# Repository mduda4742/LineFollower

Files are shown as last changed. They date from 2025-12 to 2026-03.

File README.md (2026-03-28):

# LineFollower

This project presents an autonomous Line Follower robot built around the STM32 NUCLEO-L476RG platform. The main objective is fast and accurate tracking of a black line on a white surface.

The work includes:
- 3D modeling of the robot and custom parts
- 3D printing and mechanical assembly
- PID controller implementation and tuning on NUCLEO-L476RG
- Electrical schematic design and integration of all electronic modules

## Project Overview

The robot uses a reflective sensor array to estimate the line position in real time. Based on sensor readings, a PID controller computes the correction signal and adjusts DC motor speeds independently. This approach improves cornering stability, reduces oscillations, and enables smoother trajectory tracking.

Power is provided by two Li-Ion cells, and firmware development is done in STM32CubeIDE.

## Mechanical Design (3D CAD + Printing)

The mechanical part of the project was designed as a custom 3D model and manufactured with 3D-printed components. The repository contains CAD files for the chassis and mounting elements in the `Mechanics/` directory.

## Control System (PID on STM32 NUCLEO-L476RG)

The control firmware is implemented in C for STM32L476RG. The key part is PID parameter tuning to balance:
- fast response
- stable line tracking
- minimal overshoot during turns

Firmware sources are located in `Firmware/Core/Src/` and headers in `Firmware/Core/Inc/`.

## Electrical Design

The project also includes electrical schematic development for power distribution, sensor connections, motor driving, and microcontroller integration.

## Repository Structure

- `Firmware/` - STM32 project files, startup code, HAL configuration, and PID implementation
- `Mechanics/` - 3D CAD models and assembly files
- `Hardware/` - schematic

## Demo Video
Demo: https://youtube.com/shorts/kqhGqm2l2KI?feature=share

## Photos

zlozenie_robot

zlozenie_rzeczywistosc

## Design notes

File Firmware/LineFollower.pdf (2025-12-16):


08/12/2025

## LineFollower Project Configuration Report

# 1. Description

## 1.1. Project

Project Name | LineFollower
Board Name | NUCLEO-L476RG
Generated with: | STM32CubeMX 6.0.0
Date | 12/08/2025

## 1.2. MCU

MCU Series | STM32L4
MCU Line | STM32L4x6
MCU name | STM32L476RGTx
MCU Package | LQFP64
MCU Pin number | 64

## 1.3. Core(s) information

Core(s) | Arm Cortex-M4

# 2. Pinout Configuration

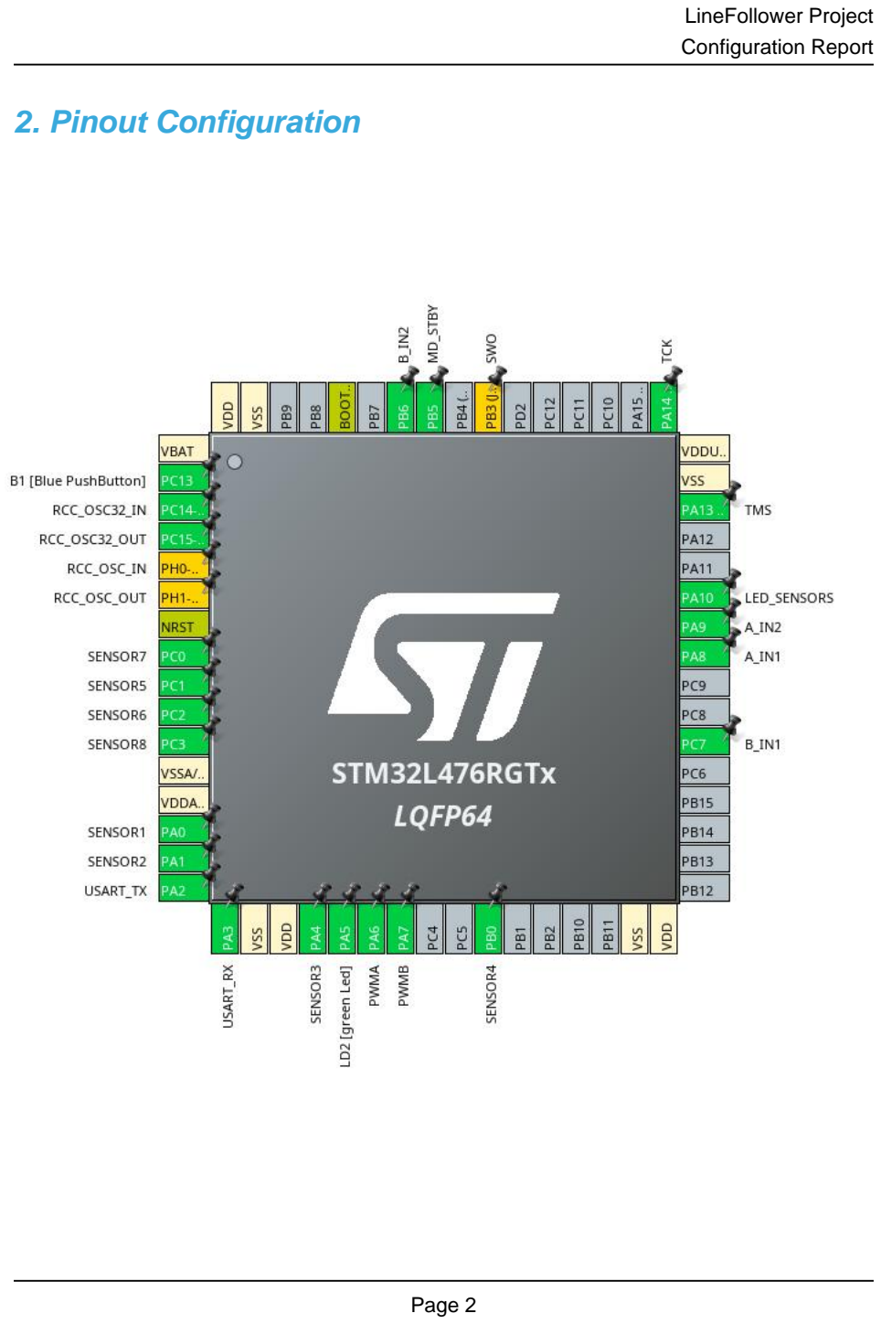
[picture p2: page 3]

# 3. Pins Configuration

Pin Number LQFP64 | Pin Name (function after reset) | Pin Type | Alternate Function(s) | Label
1 | VBAT | Power
2 | PC13 | I/O | GPIO_EXTI13 | B1 [Blue PushButton]
3 | PC14-OSC32_IN (PC14) | I/O | RCC_OSC32_IN
4 | PC15-OSC32_OUT (PC15) | I/O | RCC_OSC32_OUT
5 | PH0-OSC_IN (PH0) * | I/O | RCC_OSC_IN
6 | PH1-OSC_OUT (PH1) * | I/O | RCC_OSC_OUT
7 | NRST | Reset
8 | PC0 | I/O | ADC1_IN1 | SENSOR7
9 | PC1 | I/O | ADC1_IN2 | SENSOR5
10 | PC2 | I/O | ADC1_IN3 | SENSOR6
11 | PC3 | I/O | ADC1_IN4 | SENSOR8
12 | VSSA/VREF- | Power
13 | VDDA/VREF+ | Power
14 | PA0 | I/O | ADC1_IN5 | SENSOR1
15 | PA1 | I/O | ADC1_IN6 | SENSOR2
16 | PA2 | I/O | USART2_TX | USART_TX
17 | PA3 | I/O | USART2_RX | USART_RX
18 | VSS | Power
19 | VDD | Power
20 | PA4 | I/O | ADC1_IN9 | SENSOR3
21 | PA5 ** | I/O | GPIO_Output | LD2 [green Led]
22 | PA6 | I/O | TIM3_CH1 | PWMA
23 | PA7 | I/O | TIM3_CH2 | PWMB
26 | PB0 | I/O | ADC1_IN15 | SENSOR4
31 | VSS | Power
32 | VDD | Power
38 | PC7 ** | I/O | GPIO_Output | B_IN1
41 | PA8 ** | I/O | GPIO_Output | A_IN1
42 | PA9 ** | I/O | GPIO_Output | A_IN2
43 | PA10 ** | I/O | GPIO_Output | LED_SENSORS
46 | PA13 (JTMS-SWDIO) | I/O | SYS_JTMS-SWDIO | TMS
47 | VSS | Power
48 | VDDUSB | Power
49 | PA14 (JTCK-SWCLK) | I/O | SYS_JTCK-SWCLK | TCK
55 | PB3 (JTDO-TRACESWO) * | I/O | SYS_JTDO-SWO | SWO
57 | PB5 ** | I/O | GPIO_Output | MD_STBY

Pin Number LQFP64 | Pin Name (function after reset) | Pin Type | Alternate Function(s) | Label
58 | PB6 ** | I/O | GPIO_Output | B_IN2
60 | BOOT0 | Boot
63 | VSS | Power
64 | VDD | Power

## ** The pin is affected with an I/O function * The pin is affected with a peripheral function but no peripheral mode is activated

# 4. Clock Tree Configuration

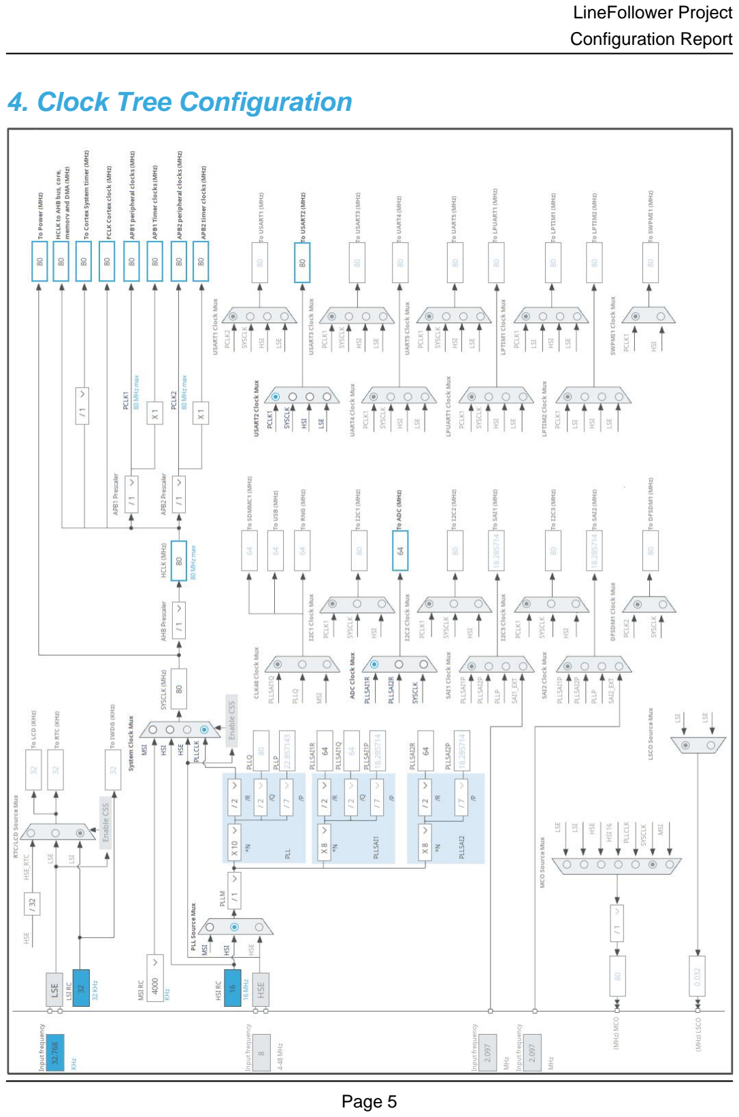
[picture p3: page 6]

# 5. Software Project

## 5.1. Project Settings

Name | Value
Project Name | LineFollower
Project Folder | /home/lukaszlysek/STM32CubeIDE/workspace_1.4.0/LineFollower
Toolchain / IDE | STM32CubeIDE
Firmware Package Name and Version | STM32Cube FW_L4 V1.16.0
Application Structure | Advanced
Generate Under Root | Yes
Do not generate the main() | No
Minimum Heap Size | 0x200
Minimum Stack Size | 0x400

## 5.2. Code Generation Settings

Name | Value
STM32Cube MCU packages and embedded software | Copy only the necessary library files
Generate peripheral initialization as a pair of '.c/.h' files | No
Backup previously generated files when re-generating | No
Keep User Code when re-generating | Yes
Delete previously generated files when not re-generated | Yes
Set all free pins as analog (to optimize the power consumption) | No
Enable Full Assert | No

## 5.3. Advanced Settings - Generated Function Calls

Rank | Function Name | IP Instance Name
1 | MX_GPIO_Init | GPIO
2 | MX_DMA_Init | DMA
3 | SystemClock_Config | RCC
4 | MX_USART2_UART_Init | USART2
5 | MX_ADC1_Init | ADC1
6 | MX_TIM3_Init | TIM3

# 6. Power Consumption Calculator report

## 6.1. Microcontroller Selection

Series | STM32L4
Line | STM32L4x6
MCU | STM32L476RGTx
Datasheet | DS10198_Rev4

## 6.2. Parameter Selection

Temperature | 25
Vdd | 3.0

## 6.3. Battery Selection

Battery | Li-SOCL2(A3400)
Capacity | 3400.0 mAh
Self Discharge | 0.08 %/month
Nominal Voltage | 3.6 V
Max Cont Current | 100.0 mA
Max Pulse Current | 200.0 mA
Cells in series | 1
Cells in parallel | 1

## 6.4. Sequence

Step | Step1 | Step2
Mode | RUN | STOP2
Vdd | 3.0 | 3.0
Voltage Source | Battery | Battery
Range | Range1-High | NoRange
Fetch Type | SRAM2 | n/a
CPU Frequency | 80 MHz | 0 Hz
Clock Configuration | HSE PLL | ALL CLOCKS OFF
Clock Source Frequency | 4 MHz | 0 Hz

### Peripherals

Additional Cons. | 0 mA | 0 mA
Average Current | 10.7 mA | 1.18 µA
Duration | 0.1 ms | 0.9 ms
DMIPS | 100.0 | 0.0
Ta Max | 103.56 | 105
Category | In DS Table | In DS Table

## 6.5. Results

Sequence Time | 1 ms | Average Current | 1.07 mA
Battery Life | 4 months, 10 days, 3 hours | Average DMIPS | 100.0 DMIPS

## 6.6. Chart

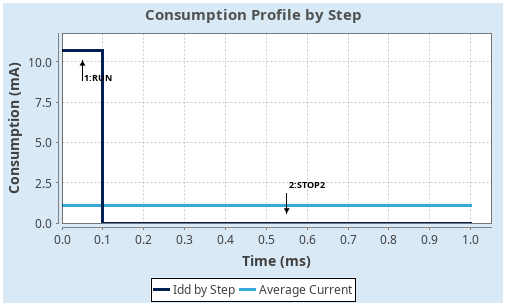
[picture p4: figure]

# 7. IPs and Middleware Configuration

## 7.1. ADC1 IN1: IN1 Single-ended IN2: IN2 Single-ended IN3: IN3 Single-ended IN4: IN4 Single-ended IN5: IN5 Single-ended IN6: IN6 Single-ended IN9: IN9 Single-ended IN15: IN15 Single-ended

## 7.1.1. Parameter Settings:

### ADCs_Common_Settings:

Mode | Independent mode

### ADC_Settings:

Clock Prescaler | Asynchronous clock mode divided by 10 *
Resolution | ADC 12-bit resolution
Data Alignment | Right alignment
Scan Conversion Mode | Enabled
Continuous Conversion Mode | Enabled *
Discontinuous Conversion Mode | Disabled
DMA Continuous Requests | Enabled *
End Of Conversion Selection | End of single conversion
Overrun behaviour | Overrun data preserved
Low Power Auto Wait | Disabled

### ADC_Regular_ConversionMode:

Enable Regular Conversions | Enable
Enable Regular Oversampling | Disable
Number Of Conversion | 8 *
External Trigger Conversion Source | Regular Conversion launched by software
External Trigger Conversion Edge | None
Rank | 1
Channel | Channel 5 *
Sampling Time | 640.5 Cycles *
Offset Number | No offset
Rank | 2 *
Channel | Channel 6 *
Sampling Time | 640.5 Cycles *

Offset Number | No offset
Rank | 3 *
Channel | Channel 9 *
Sampling Time | 640.5 Cycles *
Offset Number | No offset
Rank | 4 *
Channel | Channel 15 *
Sampling Time | 640.5 Cycles *
Offset Number | No offset
Rank | 5 *
Channel | Channel 2 *
Sampling Time | 640.5 Cycles *
Offset Number | No offset
Rank | 6 *
Channel | Channel 3 *
Sampling Time | 640.5 Cycles *
Offset Number | No offset
Rank | 7 *
Channel | Channel 1
Sampling Time | 640.5 Cycles *
Offset Number | No offset
Rank | 8 *
Channel | Channel 4 *
Sampling Time | 640.5 Cycles *
Offset Number | No offset

### ADC_Injected_ConversionMode:

Enable Injected Conversions | Disable

### Analog Watchdog 1:

Enable Analog WatchDog1 Mode | false

### Analog Watchdog 2:

Enable Analog WatchDog2 Mode | false

### Analog Watchdog 3:

Enable Analog WatchDog3 Mode | false

## 7.2. GPIO

## 7.3. RCC Low Speed Clock (LSE) : Crystal/Ceramic Resonator

## 7.3.1. Parameter Settings:

### System Parameters:

VDD voltage (V) | 3.3
Instruction Cache | Enabled
Prefetch Buffer | Enabled *
Data Cache | Enabled
Flash Latency(WS) | 4 WS (5 CPU cycle)

### RCC Parameters:

HSI Calibration Value | 16
MSI Calibration Value | 0
MSI Auto Calibration | Disabled
HSE Startup Timout Value (ms) | 100
LSE Startup Timout Value (ms) | 5000

### Power Parameters:

Power Regulator Voltage Scale | Power Regulator Voltage Scale 1

## 7.4. SYS Debug: Serial Wire Timebase Source: SysTick

## 7.5. TIM3 Clock Source : Internal Clock Channel1: PWM Generation CH1 Channel2: PWM Generation CH2

## 7.5.1. Parameter Settings:

### Counter Settings:

Prescaler (PSC - 16 bits value) | TIM3_PRESCALER *
Counter Mode | Up
Counter Period (AutoReload Register - 16 bits value ) | TIM3_PERIOD *
Internal Clock Division (CKD) | No Division
auto-reload preload | Disable

### Trigger Output (TRGO) Parameters:

Master/Slave Mode (MSM bit) | Disable (Trigger input effect not delayed)

Trigger Event Selection TRGO | Reset (UG bit from TIMx_EGR)

### Clear Input:

Clear Input Source | Disable

### PWM Generation Channel 1:

Mode | PWM mode 1
Pulse (16 bits value) | 0
Output compare preload | Enable
Fast Mode | Disable
CH Polarity | High

### PWM Generation Channel 2:

Mode | PWM mode 1
Pulse (16 bits value) | 0
Output compare preload | Enable
Fast Mode | Disable
CH Polarity | High

## 7.6. USART2 Mode: Asynchronous

## 7.6.1. Parameter Settings:

### Basic Parameters:

Baud Rate | 115200
Word Length | 8 Bits (including Parity)
Parity | None
Stop Bits | 1

### Advanced Parameters:

Data Direction | Receive and Transmit
Over Sampling | 16 Samples
Single Sample | Disable

### Advanced Features:

Auto Baudrate | Disable
TX Pin Active Level Inversion | Disable
RX Pin Active Level Inversion | Disable
Data Inversion | Disable
TX and RX Pins Swapping | Disable
Overrun | Enable
DMA on RX Error | Enable
MSB First | Disable

### * User modified value

# 8. System Configuration

## 8.1. GPIO configuration

IP | Pin | Signal | GPIO mode | GPIO pull/up pull down

## Max Speed

## User Label

ADC1 | PC0 | ADC1_IN1 | Analog mode for ADC
conversion
No pull-up and no pull-down | n/a | SENSOR7
PC1 | ADC1_IN2 | Analog mode for ADC
conversion
No pull-up and no pull-down | n/a | SENSOR5
PC2 | ADC1_IN3 | Analog mode for ADC
conversion
No pull-up and no pull-down | n/a | SENSOR6
PC3 | ADC1_IN4 | Analog mode for ADC
conversion
No pull-up and no pull-down | n/a | SENSOR8
PA0 | ADC1_IN5 | Analog mode for ADC
conversion
No pull-up and no pull-down | n/a | SENSOR1
PA1 | ADC1_IN6 | Analog mode for ADC
conversion
No pull-up and no pull-down | n/a | SENSOR2
PA4 | ADC1_IN9 | Analog mode for ADC
conversion
No pull-up and no pull-down | n/a | SENSOR3
PB0 | ADC1_IN15 | Analog mode for ADC
conversion
No pull-up and no pull-down | n/a | SENSOR4
RCC | PC14-
OSC32_IN
(PC14)
RCC_OSC32_IN | n/a | n/a | n/a

PC15-
OSC32_OU
T (PC15)

RCC_OSC32_O
UT
n/a | n/a | n/a
SYS | PA13
(JTMS-SWDIO)

SYS_JTMS-SWDIO

n/a | n/a | n/a | TMS

PA14 (JTCK-SWCLK)

SYS_JTCK-SWCLK

| | | n/a | n/a | n/a | TCK
TIM3 | PA6 | TIM3_CH1 | Alternate Function Push Pull | No pull-up and no pull-down | Low | PWMA
| PA7 | TIM3_CH2 | Alternate Function Push Pull | No pull-up and no pull-down | Low | PWMB
USART2 | PA2 | USART2_TX | Alternate Function Push Pull | No pull-up and no pull-down | Very High
*
| | | | | | USART_TX
| PA3 | USART2_RX | Alternate Function Push Pull | No pull-up and no pull-down | Very High
*
| | | | | | USART_RX
Single Mapped Signals | PH0- OSC_IN (PH0) | RCC_OSC_IN | n/a | n/a | n/a

PH1-
OSC_OUT
(PH1)
RCC_OSC_OUT | n/a | n/a | n/a
PB3 (JTDO- | SYS_JTDO- | n/a | n/a | n/a | SWO

IP | Pin | Signal | GPIO mode | GPIO pull/up pull down | Max Speed | User Label
| TRACESWO ) | SWO
GPIO | PC13 | GPIO_EXTI13 | External Interrupt Mode with Falling edge trigger detection | No pull-up and no pull-down | n/a | B1 [Blue PushButton]
| PA5 | GPIO_Output | Output Push Pull | No pull-up and no pull-down | Low | LD2 [green Led]
| PC7 | GPIO_Output | Output Push Pull | No pull-up and no pull-down | Low | B_IN1
| PA8 | GPIO_Output | Output Push Pull | No pull-up and no pull-down | Low | A_IN1
| PA9 | GPIO_Output | Output Push Pull | No pull-up and no pull-down | Low | A_IN2
| PA10 | GPIO_Output | Output Push Pull | No pull-up and no pull-down | Low | LED_SENSORS
| PB5 | GPIO_Output | Output Push Pull | No pull-up and no pull-down | Low | MD_STBY
| PB6 | GPIO_Output | Output Push Pull | No pull-up and no pull-down | Low | B_IN2

## 8.2. DMA configuration

DMA request | Stream | Direction | Priority
ADC1 | DMA1_Channel1 | Peripheral To Memory | Low

## ADC1: DMA1_Channel1 DMA request Settings:

Mode: | Circular *
Peripheral Increment: | Disable
Memory Increment: | Enable *
Peripheral Data Width: | Half Word
Memory Data Width: | Half Word

## 8.3. NVIC configuration

## 8.3.1. NVIC

Interrupt Table | Enable | Preenmption Priority | SubPriority
Non maskable interrupt | true | 0 | 0
Hard fault interrupt | true | 0 | 0
Memory management fault | true | 0 | 0
Prefetch fault, memory access fault | true | 0 | 0
Undefined instruction or illegal state | true | 0 | 0
System service call via SWI instruction | true | 0 | 0
Debug monitor | true | 0 | 0
Pendable request for system service | true | 0 | 0
System tick timer | true | 0 | 0
DMA1 channel1 global interrupt | true | 0 | 0
PVD/PVM1/PVM2/PVM3/PVM4 interrupts through EXTI lines 16/35/36/37/38 | unused
Flash global interrupt | unused
RCC global interrupt | unused
ADC1 and ADC2 interrupts | unused
TIM3 global interrupt | unused
USART2 global interrupt | unused
EXTI line[15:10] interrupts | unused
FPU global interrupt | unused

## 8.3.2. NVIC Code generation

Enabled interrupt Table | Select for init sequence ordering | Generate IRQ handler | Call HAL handler
Non maskable interrupt | true | true | false
Hard fault interrupt | true | true | false
Memory management fault | true | true | false
Prefetch fault, memory access fault | true | true | false
Undefined instruction or illegal state | true | true | false
System service call via SWI instruction | true | true | false
Debug monitor | true | true | false
Pendable request for system service | true | true | false
System tick timer | true | true | true
DMA1 channel1 global interrupt | true | true | true

### * User modified value

# 9. System Views

## 9.1. Category view 9.1.1. Current

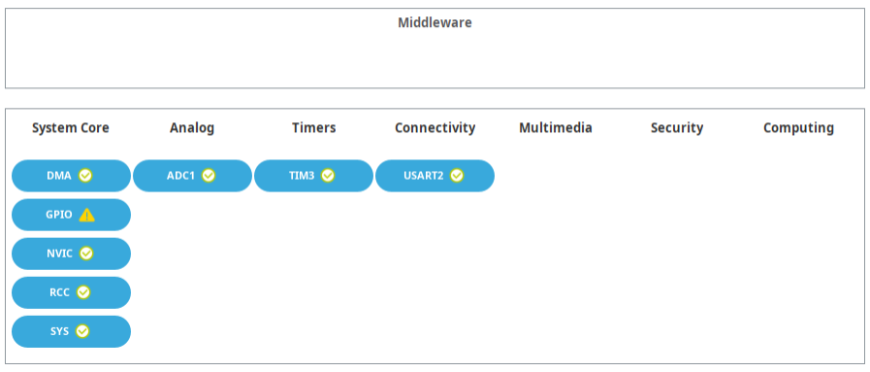
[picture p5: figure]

# 10. Docs & Resources

Type | Link
Datasheet | http://www.st.com/resource/en/datasheet/DM00108832.pdf
Reference manual | http://www.st.com/resource/en/reference_manual/DM00083560.pdf
Programming manual | http://www.st.com/resource/en/programming_manual/DM00046982.pdf
Errata sheet | http://www.st.com/resource/en/errata_sheet/DM00111498.pdf
Application note | http://www.st.com/resource/en/application_note/CD00160362.pdf
Application note | http://www.st.com/resource/en/application_note/CD00167594.pdf
Application note | http://www.st.com/resource/en/application_note/CD00211314.pdf
Application note | http://www.st.com/resource/en/application_note/CD00259245.pdf
Application note | http://www.st.com/resource/en/application_note/CD00264321.pdf
Application note | http://www.st.com/resource/en/application_note/CD00264342.pdf
Application note | http://www.st.com/resource/en/application_note/CD00264379.pdf
Application note | http://www.st.com/resource/en/application_note/DM00042534.pdf
Application note | http://www.st.com/resource/en/application_note/DM00072315.pdf
Application note | http://www.st.com/resource/en/application_note/DM00073742.pdf
Application note | http://www.st.com/resource/en/application_note/DM00073853.pdf
Application note | http://www.st.com/resource/en/application_note/DM00080497.pdf
Application note | http://www.st.com/resource/en/application_note/DM00081379.pdf
Application note | http://www.st.com/resource/en/application_note/DM00085385.pdf
Application note | http://www.st.com/resource/en/application_note/DM00087593.pdf
Application note | http://www.st.com/resource/en/application_note/DM00129215.pdf
Application note | http://www.st.com/resource/en/application_note/DM00151811.pdf
Application note | http://www.st.com/resource/en/application_note/DM00160482.pdf
Application note | http://www.st.com/resource/en/application_note/DM00156964.pdf
Application note | http://www.st.com/resource/en/application_note/DM00150423.pdf
Application note | http://www.st.com/resource/en/application_note/DM00209748.pdf

Application note | http://www.st.com/resource/en/application_note/DM00125306.pdf
Application note | http://www.st.com/resource/en/application_note/DM00141025.pdf
Application note | http://www.st.com/resource/en/application_note/DM00144612.pdf
Application note | http://www.st.com/resource/en/application_note/DM00148033.pdf
Application note | http://www.st.com/resource/en/application_note/DM00209768.pdf
Application note | http://www.st.com/resource/en/application_note/DM00216518.pdf
Application note | http://www.st.com/resource/en/application_note/DM00220769.pdf
Application note | http://www.st.com/resource/en/application_note/DM00227538.pdf
Application note | http://www.st.com/resource/en/application_note/DM00257177.pdf
Application note | http://www.st.com/resource/en/application_note/DM00269143.pdf
Application note | http://www.st.com/resource/en/application_note/DM00272912.pdf
Application note | http://www.st.com/resource/en/application_note/DM00223574.pdf
Application note | http://www.st.com/resource/en/application_note/DM00226326.pdf
Application note | http://www.st.com/resource/en/application_note/DM00236305.pdf
Application note | http://www.st.com/resource/en/application_note/DM00260952.pdf
Application note | http://www.st.com/resource/en/application_note/DM00263732.pdf
Application note | http://www.st.com/resource/en/application_note/DM00269146.pdf
Application note | http://www.st.com/resource/en/application_note/DM00296349.pdf
Application note | http://www.st.com/resource/en/application_note/DM00327191.pdf
Application note | http://www.st.com/resource/en/application_note/DM00264868.pdf
Application note | http://www.st.com/resource/en/application_note/DM00355687.pdf
Application note | http://www.st.com/resource/en/application_note/DM00311483.pdf
Application note | http://www.st.com/resource/en/application_note/DM00354244.pdf
Application note | http://www.st.com/resource/en/application_note/DM00367673.pdf
Application note | http://www.st.com/resource/en/application_note/DM00373474.pdf
Application note | http://www.st.com/resource/en/application_note/DM00315319.pdf
Application note | http://www.st.com/resource/en/application_note/DM00371863.pdf
Application note | http://www.st.com/resource/en/application_note/DM00380469.pdf
Application note | http://www.st.com/resource/en/application_note/DM00354333.pdf
Application note | http://www.st.com/resource/en/application_note/DM00395696.pdf
Application note | http://www.st.com/resource/en/application_note/DM00445657.pdf

Application note | http://www.st.com/resource/en/application_note/DM00493651.pdf
Application note | http://www.st.com/resource/en/application_note/DM00536349.pdf
Application note | http://www.st.com/resource/en/application_note/DM00209772.pdf
Application note | http://www.st.com/resource/en/application_note/DM00476869.pdf
Application note | http://www.st.com/resource/en/application_note/DM00660597.pdf
Application note | http://www.st.com/resource/en/application_note/DM00725181.pdf

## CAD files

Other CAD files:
Mechanics/assembly.f3z
Mechanics/base.f3d
Mechanics/battery_holder.f3d
Mechanics/caster_wheel.f3d
Mechanics/dc_dc_converter.f3d
Mechanics/drive_module.f3d
Mechanics/holder_bracket.f3d
Mechanics/line_sensor.f3d
Mechanics/motor_driver.f3d
Mechanics/motor_mount.f3d
Mechanics/nucleo.f3d
Mechanics/sensor_mount.f3d

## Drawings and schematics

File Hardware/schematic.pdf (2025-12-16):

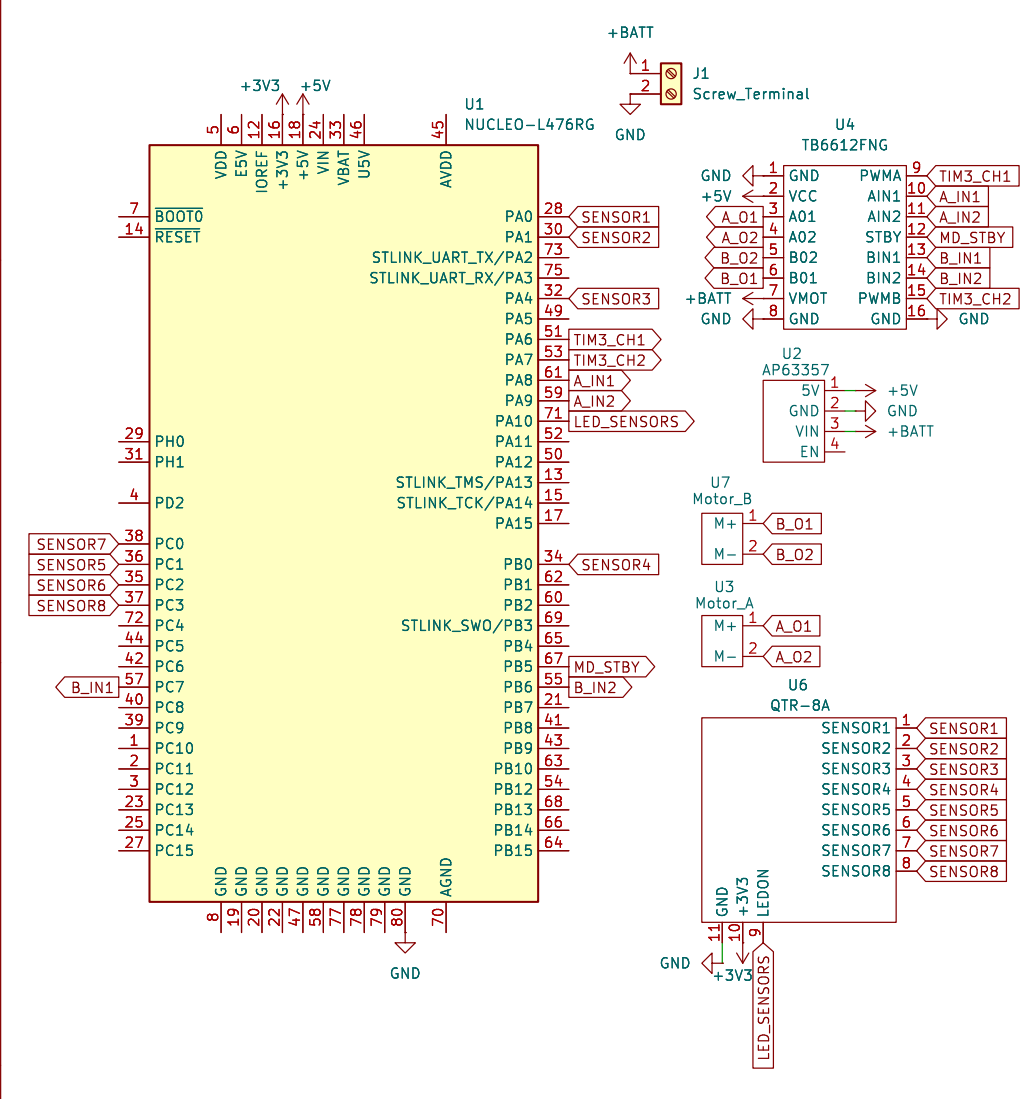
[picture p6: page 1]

5V 1 GND 2 VIN 3 EN 4 U2 AP63357 M+ 1 M- 2 U3 Motor_A GND

Id: 1/1 Title: File: Schemat_line_follower.kicad_sch Sheet: /

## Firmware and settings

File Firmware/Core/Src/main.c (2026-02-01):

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
/* Includes ------------------------------------------------------------------*/
#include "main.h"

/* USER CODE BEGIN Includes */
#include "pid.h"
/* USER CODE END Includes */

ADC_HandleTypeDef hadc1;
DMA_HandleTypeDef hdma_adc1;

TIM_HandleTypeDef htim3;
TIM_HandleTypeDef htim6;

UART_HandleTypeDef huart2;

void SystemClock_Config(void);
static void MX_GPIO_Init(void);
static void MX_DMA_Init(void);
static void MX_USART2_UART_Init(void);
static void MX_ADC1_Init(void);
static void MX_TIM3_Init(void);
static void MX_TIM6_Init(void);
/* USER CODE BEGIN 0 */
uint16_t adc_results[8];
int ADC_flag;

cpid_t pid;

const int weights[8] = {40 , 30, 20, 10, -10, -20, -30, -40};

int base_speed = 500;
int max_speed = 799;

int32_t motor_l = 0;
int32_t motor_r = 0;
int32_t u = 0;

float Kp = 15.0f;
float Ki = 0.1f;
float Kd = 10.0f;
/* USER CODE END 0 */

/**
  * @brief  The application entry point.
  * @retval int
  */
int main(void)
{
  /* MCU Configuration--------------------------------------------------------*/

  /* Reset of all peripherals, Initializes the Flash interface and the Systick. */
  HAL_Init();

  /* Configure the system clock */
  SystemClock_Config();

  /* Initialize all configured peripherals */
  MX_GPIO_Init();
  MX_DMA_Init();
  MX_USART2_UART_Init();
  MX_ADC1_Init();
  MX_TIM3_Init();
  MX_TIM6_Init();
  /* USER CODE BEGIN 2 */

  // 1. Włączenie czujnika linii
  HAL_GPIO_WritePin(LED_SENSORS_GPIO_Port, LED_SENSORS_Pin, GPIO_PIN_SET);
  HAL_Delay(20);

  // 2. Start pomiarów z czujnika
  HAL_ADC_Start_DMA(&hadc1, (uint32_t*)adc_results, 8);

  // 3. Ustawienie kierunku silników
  HAL_GPIO_WritePin(A_IN1_GPIO_Port, A_IN1_Pin, GPIO_PIN_RESET);
  HAL_GPIO_WritePin(A_IN2_GPIO_Port, A_IN2_Pin, GPIO_PIN_SET);
  HAL_GPIO_WritePin(B_IN1_GPIO_Port, B_IN1_Pin, GPIO_PIN_SET);
  HAL_GPIO_WritePin(B_IN2_GPIO_Port, B_IN2_Pin, GPIO_PIN_RESET);

  // 4. Włączenie silników
  HAL_GPIO_WritePin(MD_STBY_GPIO_Port, MD_STBY_Pin, GPIO_PIN_SET);

  // 5. PWM dla silników
  __HAL_TIM_SET_COMPARE(&htim3, TIM_CHANNEL_1, 0);
  __HAL_TIM_SET_COMPARE(&htim3, TIM_CHANNEL_2, 0);
  HAL_TIM_PWM_Start(&htim3, TIM_CHANNEL_1);
  HAL_TIM_PWM_Start(&htim3, TIM_CHANNEL_2);

  // 6. Naciśnięcie przycisku odpala robota
  while(HAL_GPIO_ReadPin(B1_GPIO_Port, B1_Pin) == GPIO_PIN_SET)
    {
        HAL_GPIO_TogglePin(LD2_GPIO_Port, LD2_Pin);
        HAL_Delay(100);
    }

  HAL_GPIO_WritePin(LD2_GPIO_Port, LD2_Pin, GPIO_PIN_SET);
  HAL_Delay(1000);

  pid_init(&pid, Kp, Ki, Kd, 10, 1);

  pid.total_max = pid_scale(&pid, 500.0f);
  pid.total_min = pid_scale(&pid, -500.0f);

  HAL_TIM_Base_Start(&htim6);

  /* USER CODE END 2 */

  /* Infinite loop */
  /* USER CODE BEGIN WHILE */

  // A - lewy
  // B - prawy
  // 1 - tył
  // 2 - przód

  while (1)
    {
	  ADC_flag = 1;
      if (ADC_flag == 1)
      {
        ADC_flag = 0;

        int32_t numerator = 0;
        int32_t denominator = 0;

        for (int i = 0; i < 8; i++)
        {
          if (adc_results[i] > 500)
          {
            numerator += weights[i];
            denominator++;
          }
        }

        if (denominator == 8) {
        	motor_l = 0;
        	motor_r = 0;
        }
        else if (denominator > 0)
        {
          int32_t error = numerator / denominator;

          u = pid_calc(&pid, error, 0);

          motor_l = base_speed - u;
          motor_r = base_speed + u;
        }
        else
        {
          if (pid.e_last > 0)
          {
            motor_l = 0;
            motor_r = max_speed;
          }
          else if (pid.e_last < 0)
          {
            motor_l = max_speed;
            motor_r = 0;
          }
        }

        if (motor_l > max_speed) motor_l = max_speed;
        if (motor_l < 0)         motor_l = 0;
        if (motor_r > max_speed) motor_r = max_speed;
        if (motor_r < 0)         motor_r = 0;

        __HAL_TIM_SET_COMPARE(&htim3, TIM_CHANNEL_1, (uint16_t)motor_r);
        __HAL_TIM_SET_COMPARE(&htim3, TIM_CHANNEL_2, (uint16_t)motor_l);
      }
    /* USER CODE END WHILE */

    }
}
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
/* USER CODE BEGIN 4 */
void HAL_ADC_ConvCpltCallback(ADC_HandleTypeDef* hadc)
{
    if (hadc->Instance == ADC1)
    {
        ADC_flag = 1;
    }
}

int _write(int file, char *ptr, int len) {
	HAL_UART_Transmit(&huart2, (uint8_t*)ptr, len, 50);
	return len;
}
/* USER CODE END 4 */
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


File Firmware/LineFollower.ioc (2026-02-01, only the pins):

Mcu.UserName=STM32L476RGTx
PA0.GPIO_Label=SENSOR1
PA0.Signal=ADCx_IN5
PA1.GPIO_Label=SENSOR2
PA1.Signal=ADCx_IN6
PA10.GPIO_Label=LED_SENSORS
PA10.Signal=GPIO_Output
PA2.GPIO_Label=USART_TX
PA2.Signal=USART2_TX
PA3.GPIO_Label=USART_RX
PA3.Signal=USART2_RX
PA4.GPIO_Label=SENSOR3
PA4.Signal=ADCx_IN9
PA5.GPIO_Label=LD2 [green Led]
PA5.Signal=GPIO_Output
PA6.GPIO_Label=PWMA
PA6.Signal=S_TIM3_CH1
PA7.GPIO_Label=PWMB
PA7.Signal=S_TIM3_CH2
PA8.GPIO_Label=A_IN1
PA8.Signal=GPIO_Output
PA9.GPIO_Label=A_IN2
PA9.Signal=GPIO_Output
PB0.GPIO_Label=SENSOR4
PB0.Signal=ADCx_IN15
PB5.GPIO_Label=MD_STBY
PB5.Signal=GPIO_Output
PB6.GPIO_Label=B_IN2
PB6.Signal=GPIO_Output
PC0.GPIO_Label=SENSOR7
PC0.Signal=ADCx_IN1
PC1.GPIO_Label=SENSOR5
PC1.Signal=ADCx_IN2
PC13.GPIO_Label=B1 [Blue PushButton]
PC13.Signal=GPXTI13
PC2.GPIO_Label=SENSOR6
PC2.Signal=ADCx_IN3
PC3.GPIO_Label=SENSOR8
PC3.Signal=ADCx_IN4
PC7.GPIO_Label=B_IN1
PC7.Signal=GPIO_Output

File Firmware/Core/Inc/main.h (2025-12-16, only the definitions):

#define TIM3_PRESCALER 3
#define TIM3_PERIOD 999
#define B1_Pin GPIO_PIN_13
#define B1_GPIO_Port GPIOC
#define SENSOR7_Pin GPIO_PIN_0
#define SENSOR7_GPIO_Port GPIOC
#define SENSOR5_Pin GPIO_PIN_1
#define SENSOR5_GPIO_Port GPIOC
#define SENSOR6_Pin GPIO_PIN_2
#define SENSOR6_GPIO_Port GPIOC
#define SENSOR8_Pin GPIO_PIN_3
#define SENSOR8_GPIO_Port GPIOC
#define SENSOR1_Pin GPIO_PIN_0
#define SENSOR1_GPIO_Port GPIOA
#define SENSOR2_Pin GPIO_PIN_1
#define SENSOR2_GPIO_Port GPIOA
#define USART_TX_Pin GPIO_PIN_2
#define USART_TX_GPIO_Port GPIOA
#define USART_RX_Pin GPIO_PIN_3
#define USART_RX_GPIO_Port GPIOA
#define SENSOR3_Pin GPIO_PIN_4
#define SENSOR3_GPIO_Port GPIOA
#define LD2_Pin GPIO_PIN_5
#define LD2_GPIO_Port GPIOA
#define PWMA_Pin GPIO_PIN_6
#define PWMA_GPIO_Port GPIOA
#define PWMB_Pin GPIO_PIN_7
#define PWMB_GPIO_Port GPIOA
#define SENSOR4_Pin GPIO_PIN_0
#define SENSOR4_GPIO_Port GPIOB
#define B_IN1_Pin GPIO_PIN_7
#define B_IN1_GPIO_Port GPIOC
#define A_IN1_Pin GPIO_PIN_8
#define A_IN1_GPIO_Port GPIOA
#define A_IN2_Pin GPIO_PIN_9
#define A_IN2_GPIO_Port GPIOA
#define LED_SENSORS_Pin GPIO_PIN_10
#define LED_SENSORS_GPIO_Port GPIOA
#define TMS_Pin GPIO_PIN_13
#define TMS_GPIO_Port GPIOA
#define TCK_Pin GPIO_PIN_14
#define TCK_GPIO_Port GPIOA
#define SWO_Pin GPIO_PIN_3
#define SWO_GPIO_Port GPIOB
#define MD_STBY_Pin GPIO_PIN_5
#define MD_STBY_GPIO_Port GPIOB
#define B_IN2_Pin GPIO_PIN_6
#define B_IN2_GPIO_Port GPIOB

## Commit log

2025-12-16 Fusion, druk 3D
    Pliki z fusion, na podstawie których zrealizowano druk 3D.
    [czujnik_linii.f3d, koszyk_na_baterie.f3d, koszyk_na_koszyk.f3d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]
2025-12-16 Sterowanie P
    [czujnik_linii.f3d, koszyk_na_baterie.f3d, koszyk_na_koszyk.f3d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]
2026-02-01 algorytm sterowania PID

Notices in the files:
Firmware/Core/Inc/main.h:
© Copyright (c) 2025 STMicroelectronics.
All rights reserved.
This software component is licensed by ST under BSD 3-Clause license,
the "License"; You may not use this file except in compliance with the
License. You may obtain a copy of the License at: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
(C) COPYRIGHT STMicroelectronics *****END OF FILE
